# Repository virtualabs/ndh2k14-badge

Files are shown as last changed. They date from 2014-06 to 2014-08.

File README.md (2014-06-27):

Nuit du Hack 2014 - Collector Badge
===================================

This repository contains code samples, binaries and other resources to code,
build and upload Arduino sketches to the NdH2k14 collector badge.

How to start ?
--------------

* Install avr-gcc and Arduino
* Install avrdude for linux or windows
* Install drivers for windows (if required)
* Try with the provided samples

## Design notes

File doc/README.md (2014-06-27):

Skullboard v2 (aka NdH2K14 Collector Badge)
===========================================

Cette board a été conçue par mes soins, et est basée sur deux projets formidables que sont USnooBie (http://eleccelerator.com/usnoobie/)
et Arduino (http://www.arduino.cc/fr/). Pour le coup, le design du circuit a permis de jouer sur la forme, et elle arbore donc une belle
tête de mort, logo de l'association HZV.

Ce document décrit les spécifications de la board, ses fonctionnalités ainsi que la manière de l'utiliser.

Spécifications techniques & fonctionnalités
-------------------------------------------

La Skullboard est basée sur un micro-contrôleur ATmega328p, qui est la base même de pas mal de boards Arduino, mais avec quelques ajustements:

* elle peut être programmée sans composant supplémentaire, via le port USB (si le micro-contrôleur possède le bon bootloader)
* elle peut communiquer via USB et émuler des périphériques HID (clavier, souris, joystick)
* elle possède un bon nombre de GPIOs permettant de s'interfacer avec divers composants
* elle possède tout un lot de pads plaqués or, qui peuvent servir à de la soudure ISO 1664
* elle peut être programmée via un connecteur ISP standard (5x2 broches), en cas de problème
* elle possède un connecteur mini-usb

L'alimentation de la board est basée sur 5V, mais cette version n'intègre pas de régulateur/limiteur.

Nomenclature
------------

La nomenclature définit les différents composants ainsi que leurs noms tels que référencés sur le circuit imprimé. Très utile si vous voulez savoir
quoi souder et où le souder.

Nom   |        Desc.
------|-------------------------------------------------------------------------
R1    | Résistance 10 kOhm
R2    | Résistance 1.5 kOhm
R3    | Résistance 68 Ohm
R4    | Résistance 68 Ohm
R5    | Résistance 330 Ohm
Z1    | Diode Zener 3.6V
Z2    | Diode Zener 3.6V
C6    | Condensateur céramique 27 pF
C7    | Condensateur céramique 100nF
C8    | Condensateur céramique 27 pF
XTAL  | Quartz 12 Mhz
PWR   | Led ronde rouge 3mm
SW1   | Bouton tactile noir
RESET | Bouton tactile noir
ISP   | Connecteur male 5x2 broches
USB   | Connecteur mini usb femelle type B
EXT   | Connecteur male 2 broches
D-,D+ | Connecteur male 4 broches (englobe D- et D+)
CONN1 | Connecteur femelle 8 broches
CONN2 | Connecteur femelle 8 broches
CONN3 | Connecteur femelle 6 broches

Guide de montage
----------------

Outils requis:

* 1 fer à souder avec petite panne
* 1 pince coupante
* 1 pince pliante
* 1 éponge
* 1 bobine d'étain
* 1 multimètre

Montage:

1.  Plier chaque résistance (R1 à R5) aux bonnes dimensions, et les souder une à une sur le circuit (ne pas insérer toutes les résistances en une fois).
2.  Plier les diodes zener Z1 et Z2, et les souder l'une après l'autre. Attention à la polarité (marquée par une barre).
3.  Insérer le quartz en place, et le souder.
4.  Monter le connecteur USB, et vérifier son insertion:
     1. Couper légèrement les pattes de fixation si nécessaire, puis les souder. S'assurer de faire de même de l'autre côté du circuit.
     2. Etamer la panne du fer, et toucher rapidement chaque broche du connecteur USB en prenant soin de faire contact avec la piste et la broche. Il faut être minutieux. Vérifier au multimètre.
5.  Monter le support de circuit intégré (28 broches) sur le circuit imprimé, et souder les deux broches opposées en diagonale. Souder les autres broches ensuite.
6.  Monter les boutons tactiles (ne pas trop forcer), et les souder un à un.
7.  Monter et souder la LED 3mm (méplat face au support CI)
8.  Monter et souder les condensateurs C6, C7 et C8
9.  Monter et souder le connecteur ISP (5x2 broches)
10. Monter et souder le connecteur 8 broches CONN2 (D3 à C2)
11. Monter et souder le connecteur 6 broches CONN3
12. Monter et souder le connecteur 8 broches CONN1 (B0 à C1)
13. Monter et souder les connecteurs: découper 2 broches pour EXT, découper 4 broches pour D- et D+.
14. Insérer les cavaliers sur D- et D+.

Vérification du circuit
-----------------------

1. Connecter le montage via le port USB, avec un voltmètre vérifier la tension aux bornes des broches 7 (+5V) et 8 (GND), elle doit être de 5V. Déconnecter l'USB.
2. Insérer le ATmega328p dans son support, tel qu'indiqué sur le circuit (les ergots doivent correspondre)
3. Maintenir appuyé le bouton SW1/BOOT, et connecter l'USB. La led doit s'allumer, et l'ordinateur détecter un périphérique compatible USB.
4. Connecter un programmateur ISP (type USBasp) et tenter de dialoguer avec le micro-contrôleur.

Programmation du micro-contrôleur par USB
-----------------------------------------

Le micro-contrôleur est compatible Arduino, ce logiciel est donc suffisant pour développer des premiers programmes sur la Skullboard. Pour programmer:

1. Sélectionner le programmateur USBasp dans le menu du logiciel Arduino IDE
2. Sélectionner la skullboard comme board cible (cf. configuration du logiciel Arduino IDE)
3. Connecter la skullboard tout en maintenant le bouton SW1/BOOT appuyé, la led s'allume
4. Programmer avec le logiciel Arduino
5. Appuyer sur le bouton RESET pour lancer le programme sur le micro-contrôleur

Programmation du micro-contrôleur par ISP
-----------------------------------------

Si vous possédez un programmateur de micro-contrôleur type USBasp ou similaire, vous pouvez programmer celui-ci via ce connecteur. Attention à ne pas écraser le bootloader.

1. Insérer le cavalier sur EXT si le programmateur fournit l'alimentation
2. Connecter le programmateur
3. Programmer
4. Appuyer sur le bouton RESET

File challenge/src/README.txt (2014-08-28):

Nuit du Hack 2014 Collector Badge
=================================

This is the source code of the firmware installed in the collector badge, including
funny things available through the minimal serial interface implemented from scratch
through V-USB (http://www.obdev.at/vusb/). 

Console.py is required to interact with the firmware.

1. Compiling
------------

$ make

This command produces a `main.hex` firmware file. If avrdude is installed on your
machine, you can plug in the badge in program mode (plug the badge, hold both reset
and boot buttons, then released the reset button, the led is on) and type:

$ make flash

2. USB interface
----------------

USB interface uses a bit of bitbanging implemented by people at Objective Development,
for more information see http://www.obdev.at/vusb/.

3. VM-related stuff
-------------------

I did not include the VM assembler I developed for this firmware, but basically the vm
is a stack-based one with a few operations. More details in `vm/vm.h` .

Serial I/O operations are also implemented in the virtual machine code.

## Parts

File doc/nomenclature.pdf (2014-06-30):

Nomenclature

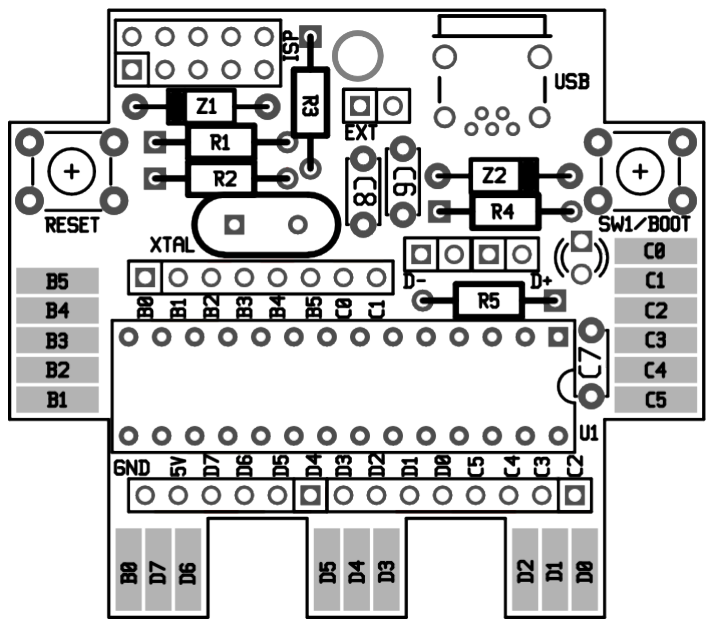
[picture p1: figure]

## Nomenclature Badge NDH

Nom | Référence | Description
R1 | | Résistance 10 kohm
R2 | | Résistance 1.5 kohm
R3 | | Résistance 68 ohm
R4 | | Résistance 68 ohm
R5 | | Résistance 330 ohm
Z1 | 1N4729A | Diode Zener 3.6V 1W
Z2 | 1N4729A | Diode Zener 3.6V 1W
C6 | | Condensateur céramique 27pF
C7 | | Condensateur céramique 100nF
C8 | | Condensateur céramique 27pF
XTAL | | Quartz 12Mhz
PWR | | Led ronde 3mm rouge
SW1 | | Bouton tactile noir
RESET | | Bouton tactile noir
ISP | | Connecteur male 5x2 broches
USB | | Connecteur femelle mini-usb type B
EXT | | Connecteur male 2 broches
D-, D+ | | Connecteur male 4 broches
CONN1 | | Connecteur femelle 8 pins
CONN2 | | Connecteur femelle 8 pins
CONN3 | | Connecteur femelle 6 pins
U1 | | Support CI PDIP 28 pins + ATmega328

Packaging

## packaging des badges collector

Composant | Qté
Résistance 68 ohms | 2
Résistance 330 ohms | 1
Résistance 1.5 kohms | 1
Résistance 10 kohms | 1
Diode zener 1N4729A | 2
Condensateur 27pF | 2
Condensateur 100nF | 1
Quartz 12Mhz | 1
Led ronde 3mm rouge | 1
Bouton tactile noir | 2
Connecteur male 5x2 pins | 1
Connecteur femelle mini-usb type B | 1
Connecteur sécable male 8 pins | 1
Connecteur femelle 8 pins | 2
Connecteur femelle 6 pins | 1
Support CI 28 pins | 1
ATmega328P | 1
Header short jumper | 2

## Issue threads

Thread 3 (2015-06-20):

Programmer not responding

Vectrixx, 2015-06-20:
Hello,
I've install all things as described but i got this error :
```
avrdude: stk500_recv(): programmer is not responding
avrdude: stk500_getsync() attempt 1 of 10: not in sync: resp=0x92
```

Is my chip dead ? I haven't tried on Unix.
King regards

virtualabs, 2015-06-21:
First of all: are you trying to program a Nuit du Hack 2014 Badge ?

If yes, you should use avrisp rather than stk500 as a programmer, by selecting the right board;

Vectrixx, 2015-06-21:
yes, that's an NDH2k14 badge.
I've selected Arduino Uno, isn't right ?

Ayzak, 2015-06-21:
You had to join a specific model, skullboard atmega 328p I think.
You can found the documentation on the github of virtualabs at badgeNDH2K14.

-----Message d'origine-----
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

virtualabs, 2015-06-21:
You should use the following boards.txt file in your arduino setup and
select the "skullboard w/ atmega328" board before compiling.

It works fine with avrdude :)
Le 21 juin 2015 18:49, "Jérémy" <notifications@github.com> a écrit :

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

Vectrixx, 2015-06-21:
Ok! Thanks !
So i've added the skullbard settings to board.txt and haven't the stk_error anymore.
Instead an other error : 'upload.tool missing' . So i added to the board.txt  :
```
skull.upload.tool=arduino:avrdude
```
It worked, but now avrdude can't find my device ...
```
avrdude: error: could not find USB device with vid=0x16c0 pid=0x5dc vendor='www.fischl.de' product='USBasp'
```

Is there an Arduino configuration tutorial available ?
I think i'll switch to avrdude  ><

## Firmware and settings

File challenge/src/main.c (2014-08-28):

/* Name: main.c
 * Project: Ndh2k14 badge challenge
 * Author: Damien Cauquil
 * License: GNU GPL v2 (see License.txt)
 *
 * Challenge consists of four main tasks:
 *
 * - Caesar encoded string (easy one)
 * - 4PPM encoded data sent out through D0, containing the flag
 * - Externally biased PRNG used with RC4 cipher
 * - little virtual machine with obfuscated instructions and junked bytecode
 *
 *
 * 1. Caesar encoded string
 *
 * The easy one. Obvious.
 *
 *
 * 2. 4PPM encoded data sent out  through D0
 *
 * This task may be defeated in two ways:
 *
 * - reverse engineering of the firmware (hardcoded RC4 encrypted string)
 * - through a logical analyzer (Raspberry Pi + piscope)
 *
 *
 * 3. Externally biased PRNG
 *
 * This tasks ask for an authentication code based on a challenge
 * to solve: this challenge is produced by an RC4-based PRNG.
 * The PRNG relies on D1 as a floating pin, which state is volatile.
 * If this pin is grounded, then it is no more floating and PRNG values
 * may be predicted.
 *
 * This test is presented as an OTP feature for a secure access. The key
 * is unciphered in memory, used to initialize a crypto context, and then
 * ciphered.
 *
 *
 * 4. Little obfuscated VM
 *
 * Access code is processed through a double checksum check, then used as a
 * decryption key to display the final URL.
 *
 */

#include <avr/io.h>
#include <avr/interrupt.h>
#include <avr/pgmspace.h>
#include <avr/wdt.h>
#include <avr/boot.h>
#include <avr/eeprom.h>
#include <util/delay.h>
#include <string.h>
#include <stdio.h>

#include "chall.h"
#include "rc4.h"
#include "serial.h"
#include "stages.h"
#include "hash.h"
#include "resources.h"
#include "vm/vm.h"

/******************************
 * Challenges stuff
 *****************************/

/**
 * Welcome
 */

void welcome(void)
{
    char code[9];
    HASH h;

    serial_print("Access code: ");
    
    memset(code, 0, 9);
    serial_readln(code, 9);
    hash(&h, code, 8);

    if (hashcmp(&h, (unsigned char *)STAGE1_HASH)) {
        stage1(code);
    }
    else if (hashcmp(&h, (unsigned char *)STAGE2_HASH)) {
        stage2(code);
    } 
    else if (hashcmp(&h, (unsigned char *)STAGE3_HASH)) {
        stage3(code);
    }
    else if (hashcmp(&h, (unsigned char *)STAGE4_HASH)) {
        stage4(code);
    }
}




/*****************************
 * Main code 
 ****************************/

int main (void)
{
    _delay_ms(10);
    
    /* Button setup */
    DDRB |= _BV(5);
    PINB = _BV(3);

    /* USB Setup */
    initForUsbConnectivity();


    /* Main loop */
    serial_print("Welcome to Ndh2k14 Secure Chip.\n\n");
    serial_print("New here ? type access code 'HelpPlz!'.\n\n");
    
    while(1)
    {
        welcome();
        poll();
    }

    return 0;
}

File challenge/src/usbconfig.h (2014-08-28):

/* Name: usbconfig.h
 * Project: V-USB, virtual USB port for Atmel's(r) AVR(r) microcontrollers
 * Author: Christian Starkjohann
 * Creation Date: 2005-04-01
 * Tabsize: 4
 * Copyright: (c) 2005 by OBJECTIVE DEVELOPMENT Software GmbH
 * License: GNU GPL v2 (see License.txt), GNU GPL v3 or proprietary (CommercialLicense.txt)
 */

#ifndef __usbconfig_h_included__
#define __usbconfig_h_included__

/*
General Description:
This file is an example configuration (with inline documentation) for the USB
driver. It configures V-USB for USB D+ connected to Port D bit 2 (which is
also hardware interrupt 0 on many devices) and USB D- to Port D bit 4. You may
wire the lines to any other port, as long as D+ is also wired to INT0 (or any
other hardware interrupt, as long as it is the highest level interrupt, see
section at the end of this file).
*/
//#define USB_PUBLIC static

/* ---------------------------- Hardware Config ---------------------------- */

#define USB_CFG_IOPORTNAME      D
/* This is the port where the USB bus is connected. When you configure it to
 * "B", the registers PORTB, PINB and DDRB will be used.
 */
#define USB_CFG_DMINUS_BIT      4
/* This is the bit number in USB_CFG_IOPORT where the USB D- line is connected.
 * This may be any bit in the port.
 */
#define USB_CFG_DPLUS_BIT       2
/* This is the bit number in USB_CFG_IOPORT where the USB D+ line is connected.
 * This may be any bit in the port. Please note that D+ must also be connected
 * to interrupt pin INT0! [You can also use other interrupts, see section
 * "Optional MCU Description" below, or you can connect D- to the interrupt, as
 * it is required if you use the USB_COUNT_SOF feature. If you use D- for the
 * interrupt, the USB interrupt will also be triggered at Start-Of-Frame
 * markers every millisecond.]
 */
#define USB_CFG_CLOCK_KHZ       (F_CPU/1000)
/* Clock rate of the AVR in kHz. Legal values are 12000, 12800, 15000, 16000,
 * 16500, 18000 and 20000. The 12.8 MHz and 16.5 MHz versions of the code
 * require no crystal, they tolerate +/- 1% deviation from the nominal
 * frequency. All other rates require a precision of 2000 ppm and thus a
 * crystal!
 * Since F_CPU should be defined to your actual clock rate anyway, you should
 * not need to modify this setting.
 */
#define USB_CFG_CHECK_CRC       0
/* Define this to 1 if you want that the driver checks integrity of incoming
 * data packets (CRC checks). CRC checks cost quite a bit of code size and are
 * currently only available for 18 MHz crystal clock. You must choose
 * USB_CFG_CLOCK_KHZ = 18000 if you enable this option.
 */

/* ----------------------- Optional Hardware Config ------------------------ */

/* #define USB_CFG_PULLUP_IOPORTNAME   D */
/* If you connect the 1.5k pullup resistor from D- to a port pin instead of
 * V+, you can connect and disconnect the device from firmware by calling
 * the macros usbDeviceConnect() and usbDeviceDisconnect() (see usbdrv.h).
 * This constant defines the port on which the pullup resistor is connected.
 */
/* #define USB_CFG_PULLUP_BIT          4 */
/* This constant defines the bit number in USB_CFG_PULLUP_IOPORT (defined
 * above) where the 1.5k pullup resistor is connected. See description
 * above for details.
 */

/* --------------------------- Functional Range ---------------------------- */
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

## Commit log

2014-06-27 "Nuit du Hack 2014" Collector Badge resources
    Contains:
    - arduino versions
2014-06-27 Documentation and arduino default boards configuraton added
2014-06-30 Ajout de la nomenclature.
2014-08-17 Added design files for Ndh2K14 Badge.
    [skullboard.sch]
2014-08-17 Added gerber files
    [skull-v2.bottom.gbr, skull-v2.bottommask.gbr, skull-v2.bottomsilk.gbr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]
